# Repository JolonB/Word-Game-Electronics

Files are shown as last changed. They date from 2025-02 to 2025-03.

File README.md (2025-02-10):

# Word-Game-Electronics

Electronics for the Word Game project.

Dimensions are based on a standard Scrabble board, because this is based on standard Scrabble (don't tell Hasbro/Mattel).

## Tiles

The game tiles represent different letters that can be used to spell words, including a blank space tile which can be used to represent any letter.
The value of each tile is determined by the resistor inside it which is read by an ADC in the quarter it is placed in.
The tiles also have a 2-terminal male connector for connecting to the board.

The size of a single tile is 0.75"x0.75" (19.05x19.05mm), but the internal circuit is smaller.

## Segments

The internal board is made up of nine segments.
These segments each manage a 5x5 section of the 15x15 board.

Each segment consists of a microcontroller with an ADC, some analog multiplexers, 25 LEDs, and 25 tile connection units.
Each unit is made up of a two-terminal female piece connector and an LED.

<!-- TBD: perhaps use a digital MUX to control MOSFET connections to each piece instead, depending on price -->

The entire board has dimensions of 15"x15" (38.1cm), but there is some small spacing between letters, although the width isn't documented anywhere.
I have seen 0.05" (1.27mm) being used in some projects, which would make the play space 11.95" (0.05\*14 + 0.75\*15). This leaves 1.455" as outer padding, although this dimension isn't too important for the electronics.

The segments are communicated with over I2C.
Using the general call address (0x00) allows all I2C devices to receive a broadcast.
The segments connect to the controller board over a 8 wire interface:
* 2x I2C (SDA + SCK)
* 1x device select / interrupt
* 2x power
* 3x ground

The device select pin works much like SPI's chip select pin, but only during provisioning.
This allows a single segment to interpret the message, despite all segment receiving it, which allows the controller to set the I2C addresses automatically.
Once the I2C address is set, the segment takes control of the pin and can use it to send interrupts to the controller.
This pin is pulled up and each side can only control the pin in open collector mode.

## Controller

The controller is the central device that handles all of the communication.
It has nine ports arranged in a 3x3 grid for connecting each of the segments too.
Connecting the segments correctly means it can automatically commission the boards to have the correct coordinates.

Besides these connections, this board will also display content on LCD screens and will have connections for buttons for each of the players to interact with.

The controller will communicate with the segments using some protocol.
I considered SPI, but the Raspberry Pi Pico SDK only supports blocking SPI reads and writes, which could lock up the program.
I also considered I2C, but that would require provisioning to set up the ID for each segment, which I would rather avoid.
The alternative would be to add a chip-select pin, like SPI, to select the I2C device and rather than using an address, just have a method for specifying whether the message can be responded to (personal) or not (broadcasted).
The same logic could be used for UART too, although UART isn't meant to have multiple slaves connected.

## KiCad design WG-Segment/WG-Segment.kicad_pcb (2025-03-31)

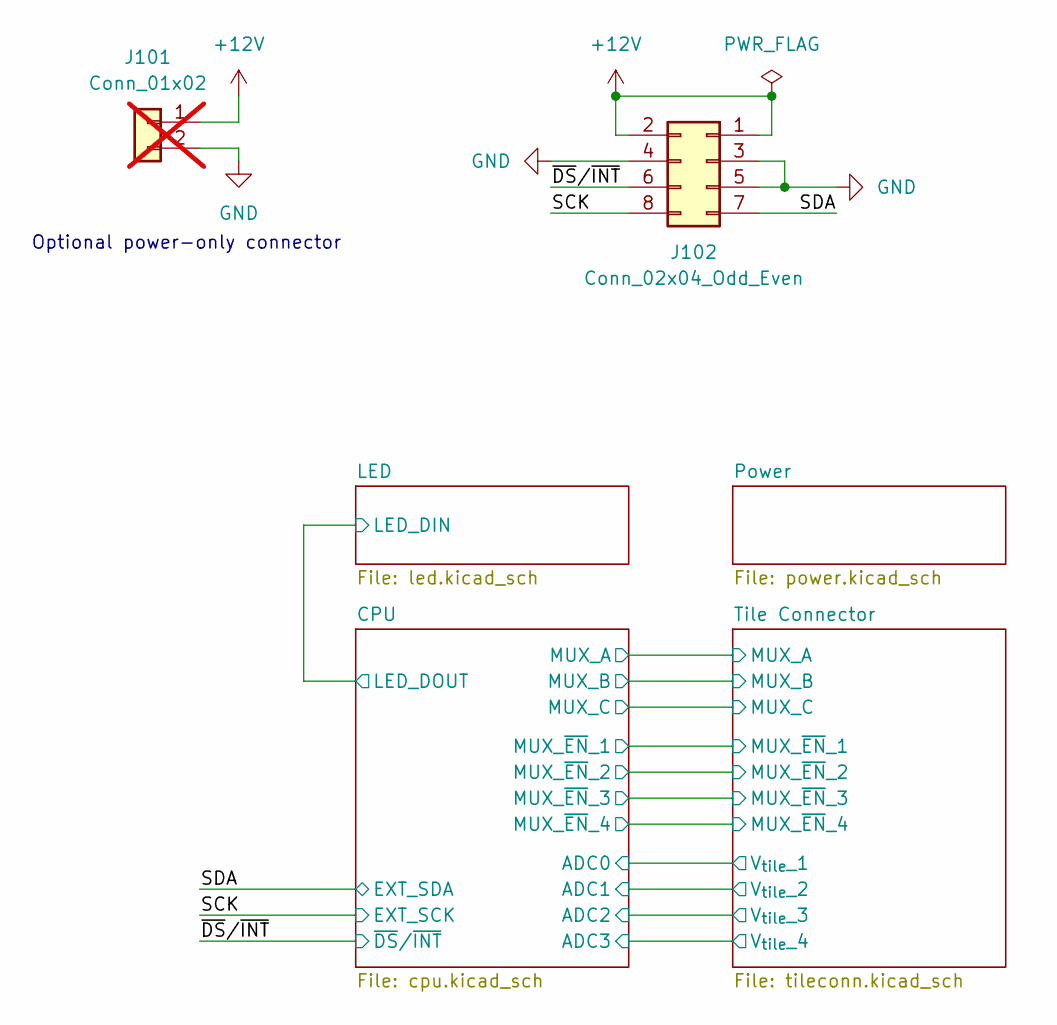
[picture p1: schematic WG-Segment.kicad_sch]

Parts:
J101: Conn_01x02; SolderWire-0.5sqmm_1x02_P4.6mm_D0.9mm_OD2.1mm; not fitted
J102: Conn_02x04_Odd_Even; JST_PHD_B8B-PHDSS_2x04_P2.00mm_Vertical; Part Number PHD-2*4A

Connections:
+12V: J101.1, J102.1, J102.2; also elsewhere on the board
/SCK: J102.8; also elsewhere on the board
/SDA: J102.7; also elsewhere on the board
/~DS/~INT: J102.6; also elsewhere on the board
GND: J101.2, J102.3, J102.4, J102.5; also elsewhere on the board

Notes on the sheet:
Optional power-only connector

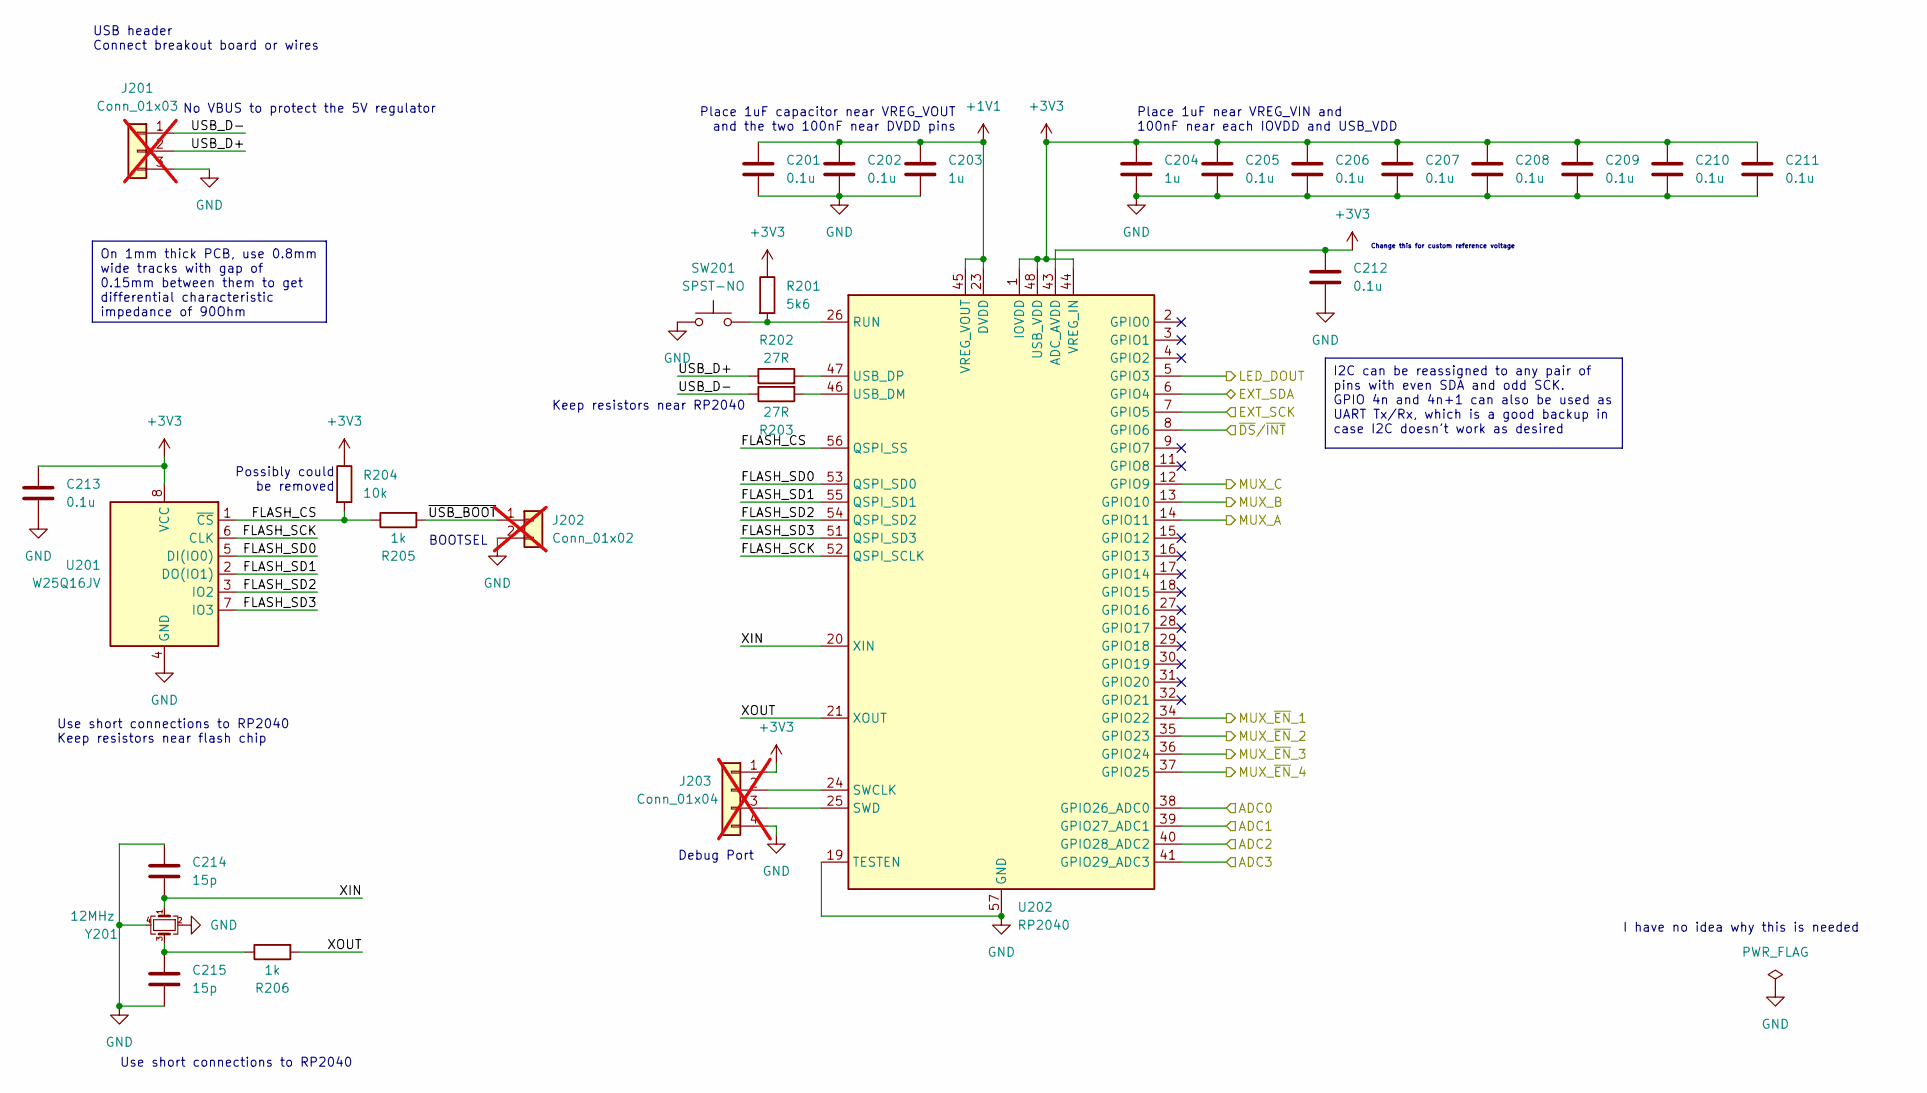
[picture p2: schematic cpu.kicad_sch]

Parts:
C201, C202, C205, C206, C207, C208, C209, C210, C211, C212, C213: 0.1u; C_0402_1005Metric_Pad0.74x0.62mm_HandSolder; LCSC Part C1525
C203, C204: 1u; C_0402_1005Metric_Pad0.74x0.62mm_HandSolder; Part Number CL05A105KA5NQNC; LCSC Part C52923
C214, C215: 15p; C_0402_1005Metric_Pad0.74x0.62mm_HandSolder; LCSC Part C1548
J201: Conn_01x03; PinHeader_1x03_P2.54mm_Vertical; not fitted
J202: Conn_01x02; PinSocket_1x02_P2.54mm_Vertical; not fitted
J203: Conn_01x04; PinHeader_1x04_P2.54mm_Vertical; not fitted
R201: 5k6; R_0402_1005Metric_Pad0.72x0.64mm_HandSolder; LCSC Part C25908
R202, R203: 27R; R_0402_1005Metric_Pad0.72x0.64mm_HandSolder
R204: 10k; R_0402_1005Metric_Pad0.72x0.64mm_HandSolder; LCSC Part C25744
R205, R206: 1k; R_0402_1005Metric_Pad0.72x0.64mm_HandSolder; LCSC Part C11702
SW201: SPST-NO; SW_SPST_PTS810; Part Number PTS810SJK250SMTR LFS
U201: W25Q16JV; SOIC-8_5.23x5.23mm_P1.27mm; Part Number W25Q16JVSSIQ; LCSC Part C131025
U202: RP2040; QFN-56-1EP_7x7mm_P0.4mm_EP3.2x3.2mm; Part Number RP2040; LCSC Part C2040
Y201: 12MHz; Crystal_SMD_Abracon_ABM8G-4Pin_3.2x2.5mm; Part Number ABM8-272-T3; LCSC Part C20625731

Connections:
+1V1: C201.1, C202.1, C203.1, U202.23 (DVDD), U202.45 (VREG_VOUT), U202.50 (DVDD)
+3V3: C204.1, C205.1, C206.1, C207.1, C208.1, C209.1, C210.1, C211.1, C212.1, C213.1, J203.1, R201.1, R204.1, U201.8 (VCC), U202.1 (IOVDD), U202.10 (IOVDD), U202.22 (IOVDD), U202.33 (IOVDD), U202.42 (IOVDD), U202.43 (ADC_AVDD), U202.44 (VREG_IN), U202.48 (USB_VDD), U202.49 (IOVDD); also elsewhere on the board
/CPU/ADC0: U202.38 (GPIO26_ADC0); also elsewhere on the board
/CPU/ADC1: U202.39 (GPIO27_ADC1); also elsewhere on the board
/CPU/ADC2: U202.40 (GPIO28_ADC2); also elsewhere on the board
/CPU/ADC3: U202.41 (GPIO29_ADC3); also elsewhere on the board
/CPU/FLASH_CS: R204.2, R205.1, U201.1 (~CS), U202.56 (QSPI_SS)
/CPU/FLASH_SCK: U201.6 (CLK), U202.52 (QSPI_SCLK)
/CPU/FLASH_SD0: U201.5 (DI(IO0)), U202.53 (QSPI_SD0)
/CPU/FLASH_SD1: U201.2 (DO(IO1)), U202.55 (QSPI_SD1)
/CPU/FLASH_SD2: U201.3 (IO2), U202.54 (QSPI_SD2)
/CPU/FLASH_SD3: U201.7 (IO3), U202.51 (QSPI_SD3)
/CPU/LED_DOUT: U202.5 (GPIO3); also elsewhere on the board
/CPU/MUX_A: U202.14 (GPIO11); also elsewhere on the board
/CPU/MUX_B: U202.13 (GPIO10); also elsewhere on the board
/CPU/MUX_C: U202.12 (GPIO9); also elsewhere on the board
/CPU/MUX_~EN_1: U202.34 (GPIO22); also elsewhere on the board
/CPU/MUX_~EN_2: U202.35 (GPIO23); also elsewhere on the board
/CPU/MUX_~EN_3: U202.36 (GPIO24); also elsewhere on the board
/CPU/MUX_~EN_4: U202.37 (GPIO25); also elsewhere on the board
/CPU/USB_D+: J201.2, R202.1
/CPU/USB_D-: J201.1, R203.1
/CPU/XIN: C214.2, U202.20 (XIN), Y201.1
/CPU/XOUT: R206.2, U202.21 (XOUT)
/CPU/~USB_BOOT: J202.1, R205.2
/SCK: U202.7 (GPIO5); also elsewhere on the board
/SDA: U202.6 (GPIO4); also elsewhere on the board
/~DS/~INT: U202.8 (GPIO6); also elsewhere on the board
GND: C201.2, C202.2, C203.2, C204.2, C205.2, C206.2, C207.2, C208.2, C209.2, C210.2, C211.2, C212.2, C213.2, C214.1, C215.2, J201.3, J202.2, J203.4, SW201.1, U201.4 (GND), U202.19 (TESTEN), U202.57 (GND), Y201.2, Y201.4; also elsewhere on the board
unnamed: C215.1, R206.1, Y201.3
unnamed: J203.2, U202.24 (SWCLK)
unnamed: J203.3, U202.25 (SWD)
unnamed: R201.2, SW201.2, U202.26 (RUN)
unnamed: R203.2, U202.46 (USB_DM)
unnamed: R202.2, U202.47 (USB_DP)

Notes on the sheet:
I2C can be reassigned to any pair of pins with even SDA and odd SCK. GPIO 4n and 4n+1 can also be used as UART Tx/Rx, which is a good backup in case I2C doesn't work as desired
On 1mm thick PCB, use 0.8mm wide tracks with gap of 0.15mm between them to get differential characteristic impedance of 90Ohm
USB header Connect breakout board or wires
I have no idea why this is needed
Keep resistors near RP2040
Debug Port
Use short connections to RP2040
No VBUS to protect the 5V regulator
Place 1uF near VREG_VIN and 100nF near each IOVDD and USB_VDD
Change this for custom reference voltage
Possibly could be removed
Use short connections to RP2040 Keep resistors near flash chip
Place 1uF capacitor near VREG_VOUT and the two 100nF near DVDD pins
BOOTSEL

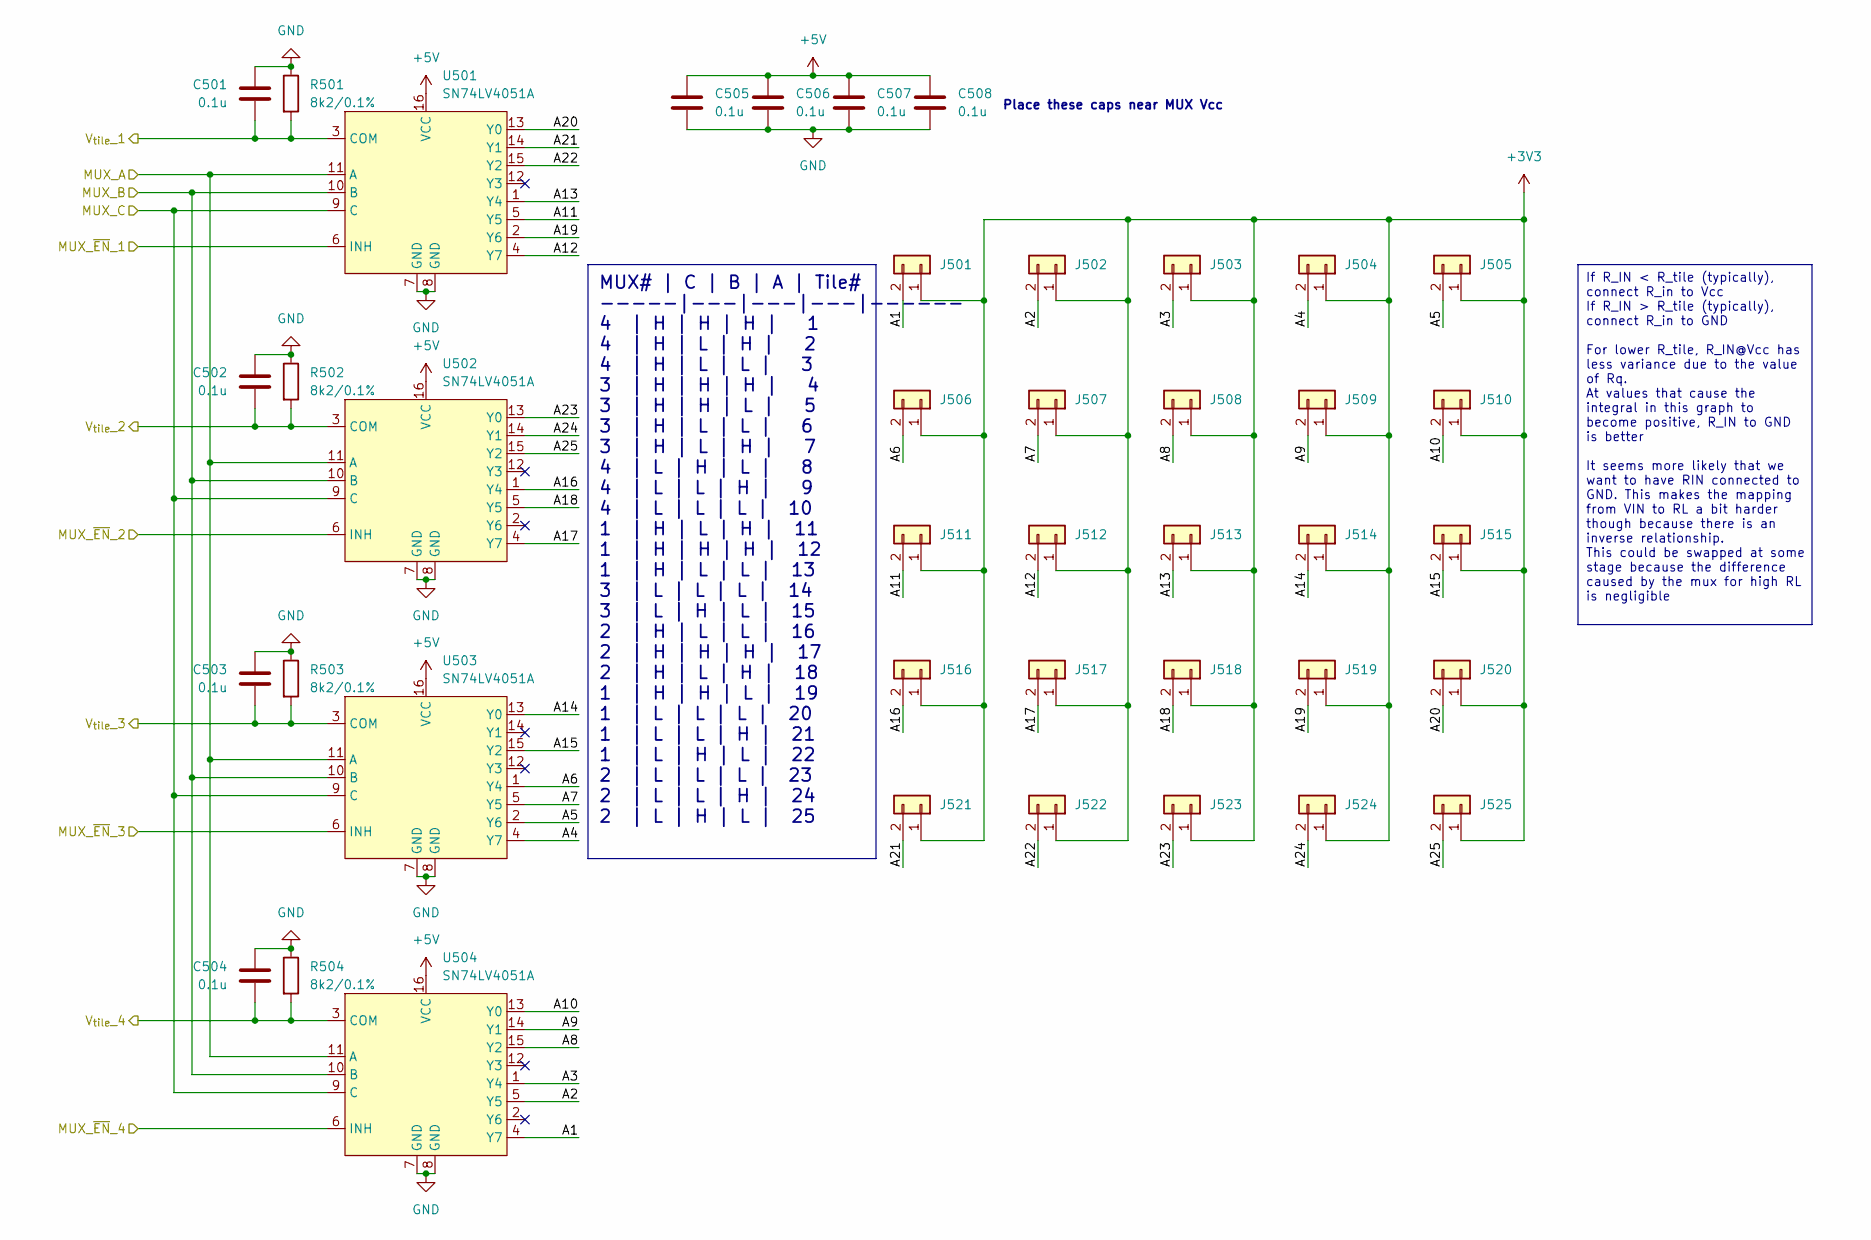
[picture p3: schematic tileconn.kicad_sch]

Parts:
C501, C502, C503, C504, C505, C506, C507, C508: 0.1u; C_0402_1005Metric_Pad0.74x0.62mm_HandSolder; LCSC Part C1525
J501, J502, J503, J504, J505, J506, J507, J508, J509, J510, J511, J512, J513, J514, J515, J516, J517, J518, J519, J520, J521, J522, J523, J524, J525: Conn_01x02; PinHeader_2x01_P1.00mm_Vertical
R501, R502, R503, R504: 8k2/0.1%; R_0402_1005Metric_Pad0.72x0.64mm_HandSolder; LCSC Part C25924
U501, U502, U503, U504: SN74LV4051A; TSSOP-16_4.4x5mm_P0.65mm; Part Number SN74LV4051APWR; LCSC Part C7793

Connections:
+3V3: J501.1, J502.1, J503.1, J504.1, J505.1, J506.1, J507.1, J508.1, J509.1, J510.1, J511.1, J512.1, J513.1, J514.1, J515.1, J516.1, J517.1, J518.1, J519.1, J520.1, J521.1, J522.1, J523.1, J524.1, J525.1; also elsewhere on the board
+5V: C505.1, C506.1, C507.1, C508.1, U501.16 (VCC), U502.16 (VCC), U503.16 (VCC), U504.16 (VCC); also elsewhere on the board
/CPU/ADC0: C501.1, R501.2, U501.3 (COM); also elsewhere on the board
/CPU/ADC1: C502.1, R502.2, U502.3 (COM); also elsewhere on the board
/CPU/ADC2: C503.1, R503.2, U503.3 (COM); also elsewhere on the board
/CPU/ADC3: C504.1, R504.2, U504.3 (COM); also elsewhere on the board
/CPU/MUX_A: U501.11 (A), U502.11 (A), U503.11 (A), U504.11 (A); also elsewhere on the board
/CPU/MUX_B: U501.10 (B), U502.10 (B), U503.10 (B), U504.10 (B); also elsewhere on the board
/CPU/MUX_C: U501.9 (C), U502.9 (C), U503.9 (C), U504.9 (C); also elsewhere on the board
/CPU/MUX_~EN_1: U501.6 (INH); also elsewhere on the board
/CPU/MUX_~EN_2: U502.6 (INH); also elsewhere on the board
/CPU/MUX_~EN_3: U503.6 (INH); also elsewhere on the board
/CPU/MUX_~EN_4: U504.6 (INH); also elsewhere on the board
/Tile Connector/A1: J501.2, U504.4 (Y7)
/Tile Connector/A2: J502.2, U504.5 (Y5)
/Tile Connector/A3: J503.2, U504.1 (Y4)
/Tile Connector/A4: J504.2, U503.4 (Y7)
/Tile Connector/A5: J505.2, U503.2 (Y6)
/Tile Connector/A6: J506.2, U503.1 (Y4)
/Tile Connector/A7: J507.2, U503.5 (Y5)
/Tile Connector/A8: J508.2, U504.15 (Y2)
/Tile Connector/A9: J509.2, U504.14 (Y1)
/Tile Connector/A10: J510.2, U504.13 (Y0)
/Tile Connector/A11: J511.2, U501.5 (Y5)
/Tile Connector/A12: J512.2, U501.4 (Y7)
/Tile Connector/A13: J513.2, U501.1 (Y4)
/Tile Connector/A14: J514.2, U503.13 (Y0)
/Tile Connector/A15: J515.2, U503.15 (Y2)
/Tile Connector/A16: J516.2, U502.1 (Y4)
/Tile Connector/A17: J517.2, U502.4 (Y7)
/Tile Connector/A18: J518.2, U502.5 (Y5)
/Tile Connector/A19: J519.2, U501.2 (Y6)
/Tile Connector/A20: J520.2, U501.13 (Y0)
/Tile Connector/A21: J521.2, U501.14 (Y1)
/Tile Connector/A22: J522.2, U501.15 (Y2)
/Tile Connector/A23: J523.2, U502.13 (Y0)
/Tile Connector/A24: J524.2, U502.14 (Y1)
/Tile Connector/A25: J525.2, U502.15 (Y2)
GND: C501.2, C502.2, C503.2, C504.2, C505.2, C506.2, C507.2, C508.2, R501.1, R502.1, R503.1, R504.1, U501.7 (GND), U501.8 (GND), U502.7 (GND), U502.8 (GND), U503.7 (GND), U503.8 (GND), U504.7 (GND), U504.8 (GND); also elsewhere on the board

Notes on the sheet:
If R_IN < R_tile (typically), connect R_in to Vcc If R_IN > R_tile (typically), connect R_in to GND For lower R_tile, R_IN@Vcc has less variance due to the value of Rq. At values that cause the integral in this graph to become positive, R_IN to GND is better It seems more likely that we want to hav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
MUX# | C | B | A | Tile# -----|---|---|---|------ 4 | H | H | H | 1 4 | H | L | H | 2 4 | H | L | L | 3 3 | H | H | H | 4 3 | H | H | L | 5 3 | H | L | L | 6 3 | H | L | H | 7 4 | L | H | L | 8 4 | L | L | H | 9 4 | L | L | L | 10 1 | H | L | H | 11 1 | H | H | H | 12 1 | H | L | L | 13 3 | L | L |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
Place these caps near MUX Vcc

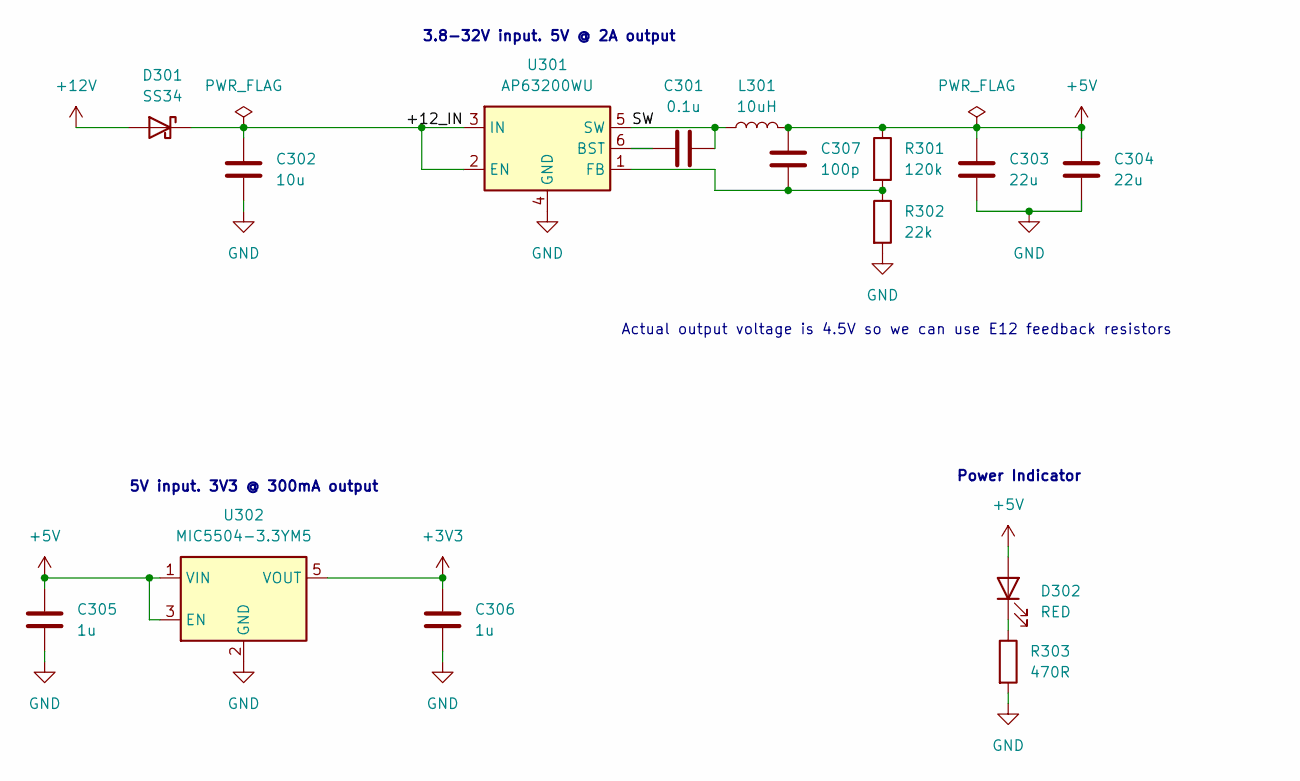
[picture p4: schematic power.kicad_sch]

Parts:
C301: 0.1u; C_0402_1005Metric_Pad0.74x0.62mm_HandSolder; LCSC Part C1525
C302: 10u; C_0805_2012Metric_Pad1.18x1.45mm_HandSolder; Part Number CL21A106KAYNNNE; LCSC Part C15850
C303, C304: 22u; C_0805_2012Metric_Pad1.18x1.45mm_HandSolder; Part Number CL21A226MAQNNNE; LCSC Part C45783
C305, C306: 1u; C_0402_1005Metric_Pad0.74x0.62mm_HandSolder; Part Number CL05A105KA5NQNC; LCSC Part C52923
C307: 100p; C_0402_1005Metric_Pad0.74x0.62mm_HandSolder; LCSC Part C1546
D301: SS34; D_SMA; Part Number SS34; LCSC Part C8678
D302: RED; LED_0603_1608Metric_Pad1.05x0.95mm_HandSolder; Part Number XL-1608SURC-06; LCSC Part C2286
L301: 10uH; Murata_6060; Part Number 1264EY-100M=P3
R301: 120k; R_0402_1005Metric_Pad0.72x0.64mm_HandSolder; LCSC Part C25750
R302: 22k; R_0402_1005Metric_Pad0.72x0.64mm_HandSolder; LCSC Part C25768
R303: 470R; R_0402_1005Metric_Pad0.72x0.64mm_HandSolder; LCSC Part C25117
U301: AP63200WU; TSOT-23-6; Part Number AP63200WU-7; LCSC Part C2071868
U302: MIC5504-3.3YM5; SOT-23-5_HandSoldering; Part Number MIC5504-3.3YM5; LCSC Part C88419

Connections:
+3V3: C306.1, U302.5 (VOUT); also elsewhere on the board
+5V: C303.1, C304.1, C305.1, C307.1, D302.2 (A), L301.2, R301.1, U302.1 (VIN), U302.3 (EN); also elsewhere on the board
+12V: D301.2 (A); also elsewhere on the board
/Power/+12_IN: C302.1, D301.1 (K), U301.2 (EN), U301.3 (IN)
/Power/SW: C301.2, L301.1, U301.5 (SW)
GND: C302.2, C303.2, C304.2, C305.2, C306.2, R302.2, R303.2, U301.4 (GND), U302.2 (GND); also elsewhere on the board
unnamed: D302.1 (K), R303.1
unnamed: C301.1, U301.6 (BST)
unnamed: C307.2, R301.2, R302.1, U301.1 (FB)

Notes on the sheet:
Actual output voltage is 4.5V so we can use E12 feedback resistors
3.8-32V input. 5V @ 2A output
Power Indicator
5V input. 3V3 @ 300mA output

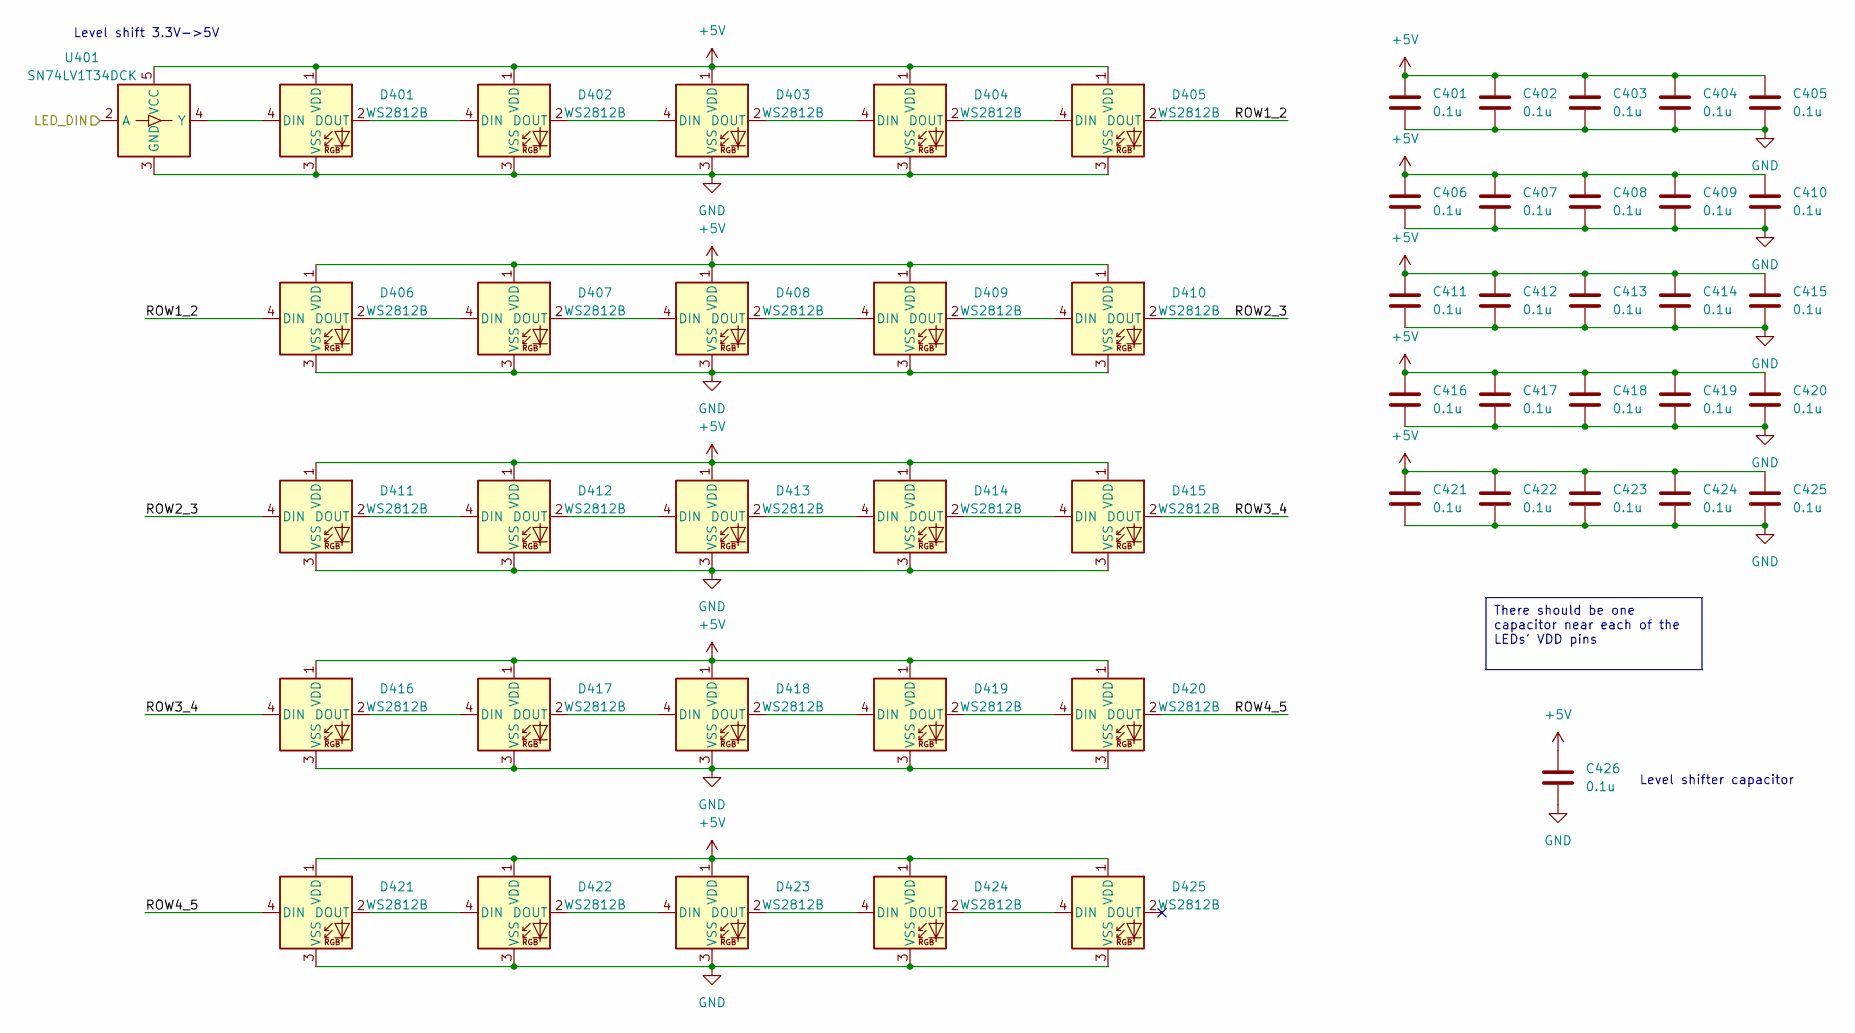
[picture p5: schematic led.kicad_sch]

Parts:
C401, C402, C403, C404, C405, C406, C407, C408, C409, C410, C411, C412, C413, C414, C415, C416, C417, C418, C419, C420, C421, C422, C423, C424, C425, C426: 0.1u; C_0402_1005Metric_Pad0.74x0.62mm_HandSolder; LCSC Part C1525
D401, D402, D403, D404, D405, D406, D407, D408, D409, D410, D411, D412, D413, D414, D415, D416, D417, D418, D419, D420, D421, D422, D423, D424, D425: WS2812B; LED_WS2812B_PLCC4_5.0x5.0mm_P3.2mm; Part Number WS2812B
U401: SN74LV1T34DCK; SOT-353_SC-70-5_Handsoldering; Part Number SN74LV1T34DCKR; LCSC Part C78541

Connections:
+5V: C401.1, C402.1, C403.1, C404.1, C405.1, C406.1, C407.1, C408.1, C409.1, C410.1, C411.1, C412.1, C413.1, C414.1, C415.1, C416.1, C417.1, C418.1, C419.1, C420.1, C421.1, C422.1, C423.1, C424.1, C425.1, C426.1, D401.1 (VDD), D402.1 (VDD), D403.1 (VDD), D404.1 (VDD), D405.1 (VDD), D406.1 (VDD), D407.1 (VDD), D408.1 (VDD), D409.1 (VDD), D410.1 (VDD), D411.1 (VDD), D412.1 (VDD), D413.1 (VDD), D414.1 (VDD), D415.1 (VDD), D416.1 (VDD), D417.1 (VDD), D418.1 (VDD), D419.1 (VDD), D420.1 (VDD), D421.1 (VDD), D422.1 (VDD), D423.1 (VDD), D424.1 (VDD), D425.1 (VDD), U401.5 (VCC); also elsewhere on the board
/CPU/LED_DOUT: U401.2 (A); also elsewhere on the board
/LED/ROW1_2: D405.2 (DOUT), D406.4 (DIN)
/LED/ROW2_3: D410.2 (DOUT), D411.4 (DIN)
/LED/ROW3_4: D415.2 (DOUT), D416.4 (DIN)
/LED/ROW4_5: D420.2 (DOUT), D421.4 (DIN)
GND: C401.2, C402.2, C403.2, C404.2, C405.2, C406.2, C407.2, C408.2, C409.2, C410.2, C411.2, C412.2, C413.2, C414.2, C415.2, C416.2, C417.2, C418.2, C419.2, C420.2, C421.2, C422.2, C423.2, C424.2, C425.2, C426.2, D401.3 (VSS), D402.3 (VSS), D403.3 (VSS), D404.3 (VSS), D405.3 (VSS), D406.3 (VSS), D407.3 (VSS), D408.3 (VSS), D409.3 (VSS), D410.3 (VSS), D411.3 (VSS), D412.3 (VSS), D413.3 (VSS), D414.3 (VSS), D415.3 (VSS), D416.3 (VSS), D417.3 (VSS), D418.3 (VSS), D419.3 (VSS), D420.3 (VSS), D421.3 (VSS), D422.3 (VSS), D423.3 (VSS), D424.3 (VSS), D425.3 (VSS), U401.3 (GND); also elsewhere on the board
unnamed: D401.4 (DIN), U401.4 (Y)
unnamed: D401.2 (DOUT), D402.4 (DIN)
unnamed: D402.2 (DOUT), D403.4 (DIN)
unnamed: D403.2 (DOUT), D404.4 (DIN)
unnamed: D404.2 (DOUT), D405.4 (DIN)
unnamed: D406.2 (DOUT), D407.4 (DIN)
unnamed: D407.2 (DOUT), D408.4 (DIN)
unnamed: D408.2 (DOUT), D409.4 (DIN)
unnamed: D409.2 (DOUT), D410.4 (DIN)
unnamed: D411.2 (DOUT), D412.4 (DIN)
unnamed: D412.2 (DOUT), D413.4 (DIN)
unnamed: D413.2 (DOUT), D414.4 (DIN)
unnamed: D414.2 (DOUT), D415.4 (DIN)
unnamed: D416.2 (DOUT), D417.4 (DIN)
unnamed: D417.2 (DOUT), D418.4 (DIN)
unnamed: D418.2 (DOUT), D419.4 (DIN)
unnamed: D419.2 (DOUT), D420.4 (DIN)
unnamed: D421.2 (DOUT), D422.4 (DIN)
unnamed: D422.2 (DOUT), D423.4 (DIN)
unnamed: D423.2 (DOUT), D424.4 (DIN)
unnamed: D424.2 (DOUT), D425.4 (DIN)

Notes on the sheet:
There should be one capacitor near each of the LEDs' VDD pins
Level shift 3.3V->5V
Level shifter capacitor

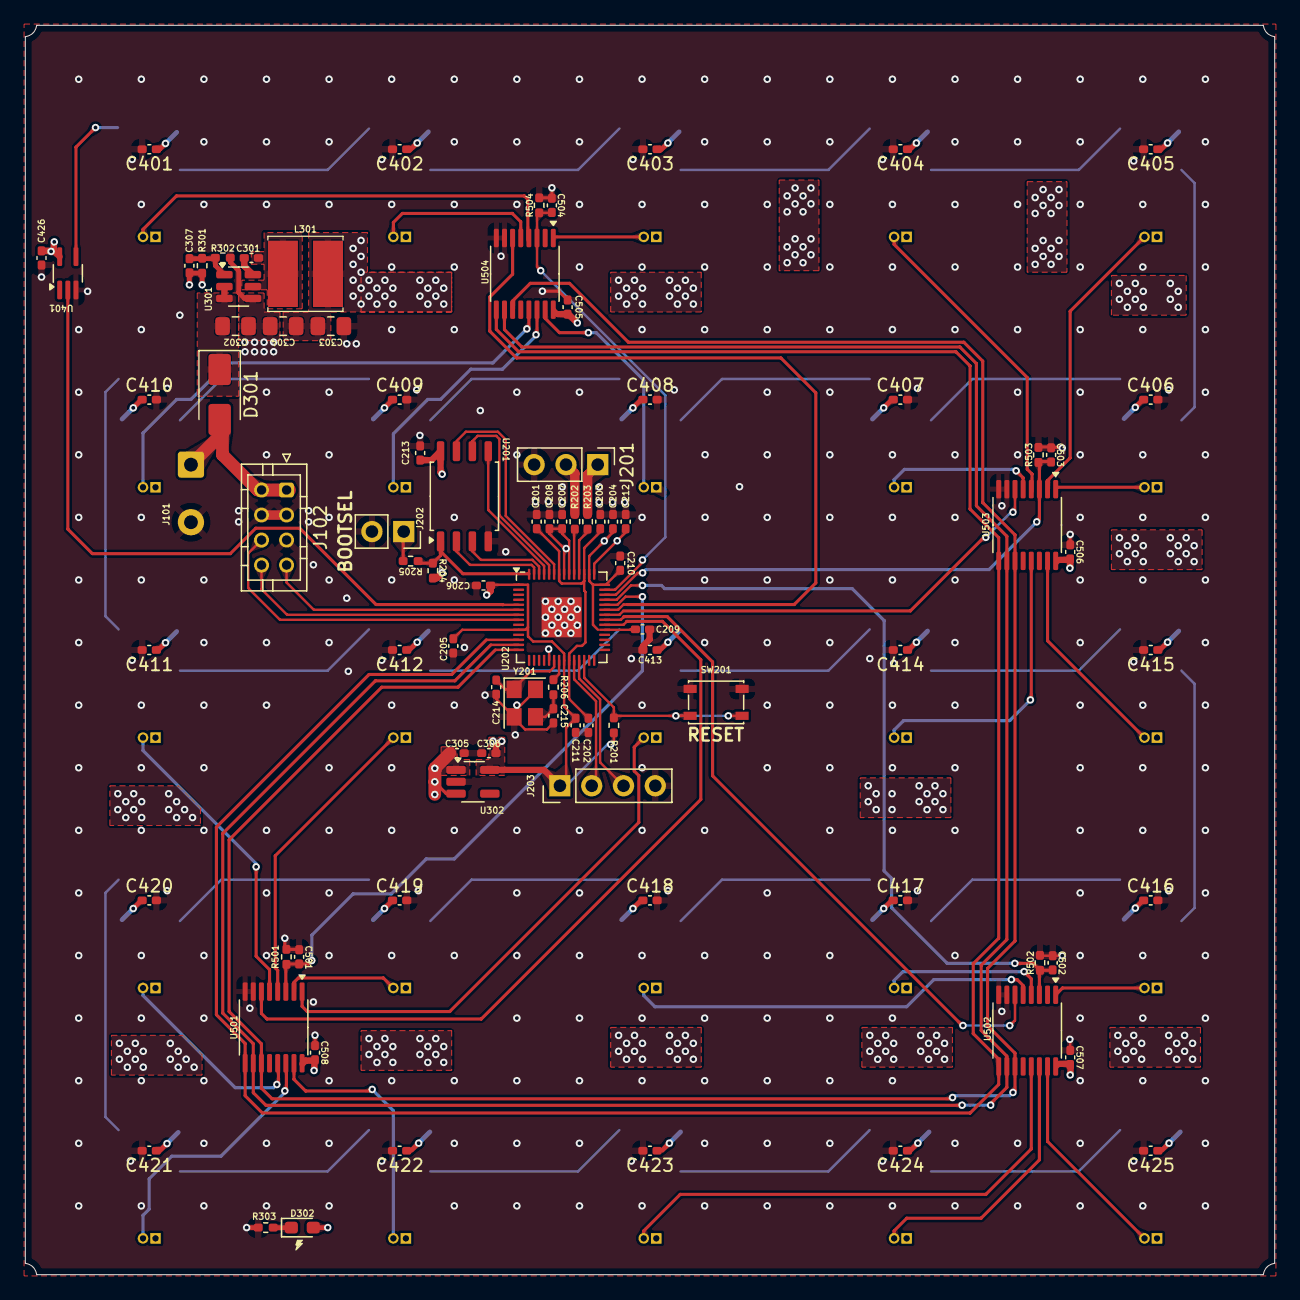
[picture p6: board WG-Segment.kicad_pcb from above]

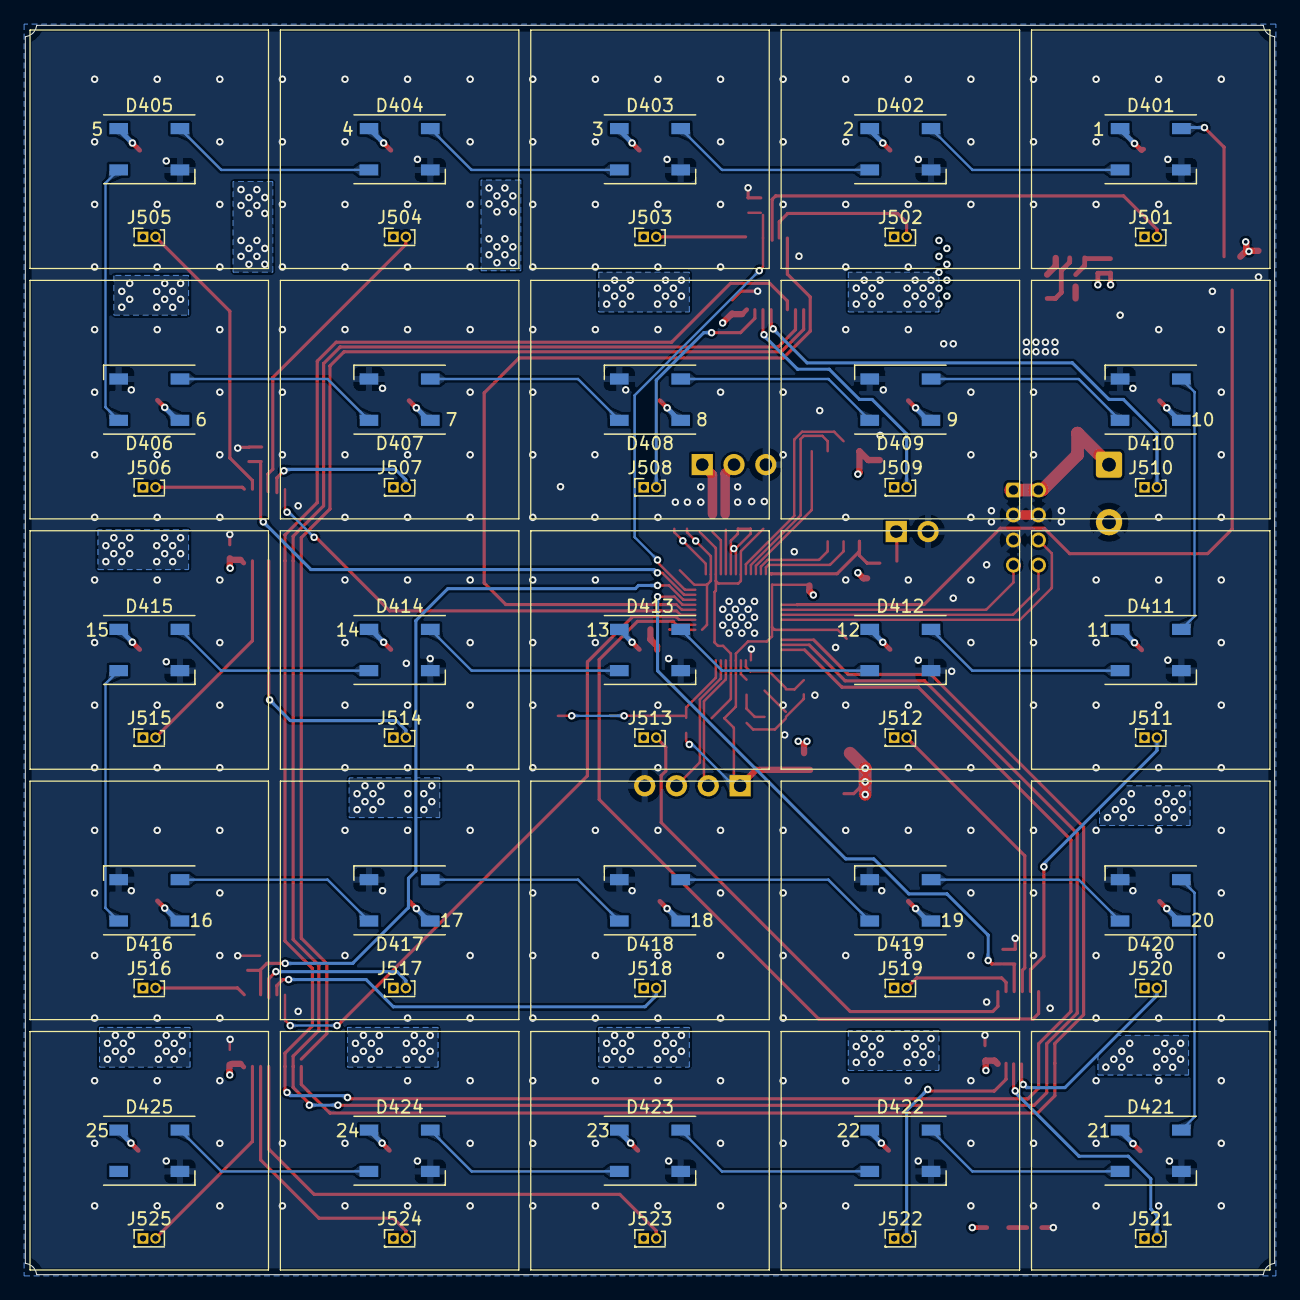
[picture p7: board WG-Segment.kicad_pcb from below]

Board: 4 copper layers, 99.8 x 99.8 mm, 138 parts (50 on the bottom side), 92 nets.

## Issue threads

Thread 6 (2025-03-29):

Make fixes to schematic

JolonB, 2025-03-29:
- [x] Change C307 description to be a 470nF capacitor
- [x] Fix font of truth table so it doesn't change when workflow runs
- [x] C308 description should say 0402
- [x] ~Consider changing R301 to different footprint to find more that fit~ Might not work because there are no 157k resistors at JLC. Maybe need to find a different pair of resistors (maybe 150k and 27k?, or an even closer ratio - ended up using 120k and 22k for a 4.5V output)
- [ ] Add layer stackup
- [x] Add JLCPCB part numbers

JolonB, 2025-03-31:
Rather than changing C307, I removed it along with the REF3033 precision voltage reference. The ADC should be taking a ratiometric reading anyway, so the same source should be suitable, and it saves money because the REF3033 is an extended part from JLCPCB

JolonB, 2025-03-31:
Decided I don't really need to add the layer stackup. Kinda pointless because we don't care that much about signal integrity and the likes

Closed 2025-03-31.

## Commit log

2025-02-04 Add empty projects
    [WG-Controller.kicad_pcb, WG-Controller.kicad_sch, WG-Tile.kicad_pcb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]
2025-02-04 Create some of the segment piece
    [WG-Segment.kicad_pcb, WG-Segment.kicad_sch, cpu.kicad_sch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]
2025-03-24 Add BOM and position files to workflow
2025-03-24 Move bom generation to sch
    Also reduce to kicad7
2025-03-24 Specify BOM columns
2025-03-25 Design full circuit
    Still need to run ERC
    [WG-Segment.kicad_sch, cpu.kicad_sch, led.kicad_sch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]
2025-03-25 Add level shifter to LED data input
    [cpu.kicad_sch, led.kicad_sch, power.kicad_sch]
2025-03-25 Set up PCB
    [WG-Segment.kicad_pcb]
2025-03-25 Add 5x5 LED grid to PCB
    [WG-Segment.kicad_pcb]
2025-03-25 Position power circuitry
    [WG-Segment.kicad_pcb, cpu.kicad_sch, power.kicad_sch]
2025-03-25 Finish designing most of the PCB
    Only need to connect analog traces. May need to make the board a 4-layer PCB
    [WG-Segment.kicad_pcb, WG-Segment.kicad_sch, cpu.kicad_sch]
2025-03-25 Change PCB to 4 layers
    Also fix all errors
    [WG-Segment.kicad_pcb]
2025-03-25 Add ADC-tile connections
    [WG-Segment.kicad_pcb, cpu.kicad_sch, tileconn.kicad_sch]
2025-03-25 Fix DRC errors
    [WG-Segment.kicad_pcb]
2025-03-25 Remote TODO
    [cpu.kicad_sch]
2025-03-25 Update connector
    [WG-Segment.kicad_pcb, WG-Segment.kicad_sch]
2025-03-25 Minor pinout adjustments
    [WG-Segment.kicad_pcb, cpu.kicad_sch]
2025-03-25 Fix build issues
    [WG-Segment.kicad_pcb, WG-Segment.kicad_sch, cpu.kicad_sch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]
2025-03-25 Change component value
    [power.kicad_sch, tileconn.kicad_sch]
2025-03-25 Add tolerances and dimensions
    [WG-Segment.kicad_pcb]
2025-03-25 Update parts to ones in JLCPCB library
    [WG-Segment.kicad_pcb, power.kicad_sch, tileconn.kicad_sch]
2025-03-29 Update regulator
    [WG-Segment.kicad_pcb, power.kicad_sch]
2025-03-30 Allow generating 4-layer PCBs
    [WG-Segment.kicad_pcb]
2025-03-31 Updates for smoother JLCPCB ordering
    [cpu.kicad_sch, power.kicad_sch, tileconn.kicad_sch]
2025-03-31 Add LCSC part numbers
    [WG-Segment.kicad_pcb, cpu.kicad_sch, led.kicad_sch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]
